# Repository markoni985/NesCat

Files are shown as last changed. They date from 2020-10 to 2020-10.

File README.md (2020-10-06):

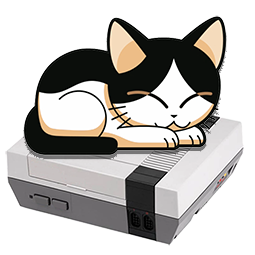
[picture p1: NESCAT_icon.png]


# NesCat 0.5

NESCAT by Nathalis
prototype version: 0.5 (c)2020
Enhanced version Nintendo Emulator for ESP32

Requirements: ESP32 WEMOS D1 MINI, ST7789 LCD, MICROSD CARD slot,
PCM5102 I2S AUDIO MODULE, OTHER PARTS...

### FEATURES:

- MicroSD card support
- 240*240 1.3" LCD ST7789 display                  
- Composite TV OUT Video PAL
- I2S AUDIO support PCM5102 module
- PS2 (USB) KEYBOARD support (wireless not work)
- huge NES ROMs up to 512kB (read from FLASH)
- PS4 DualShock BlueTooth Gamepad (experimental)

Only for personal & educational use! 

### DIAGRAM (NEW)
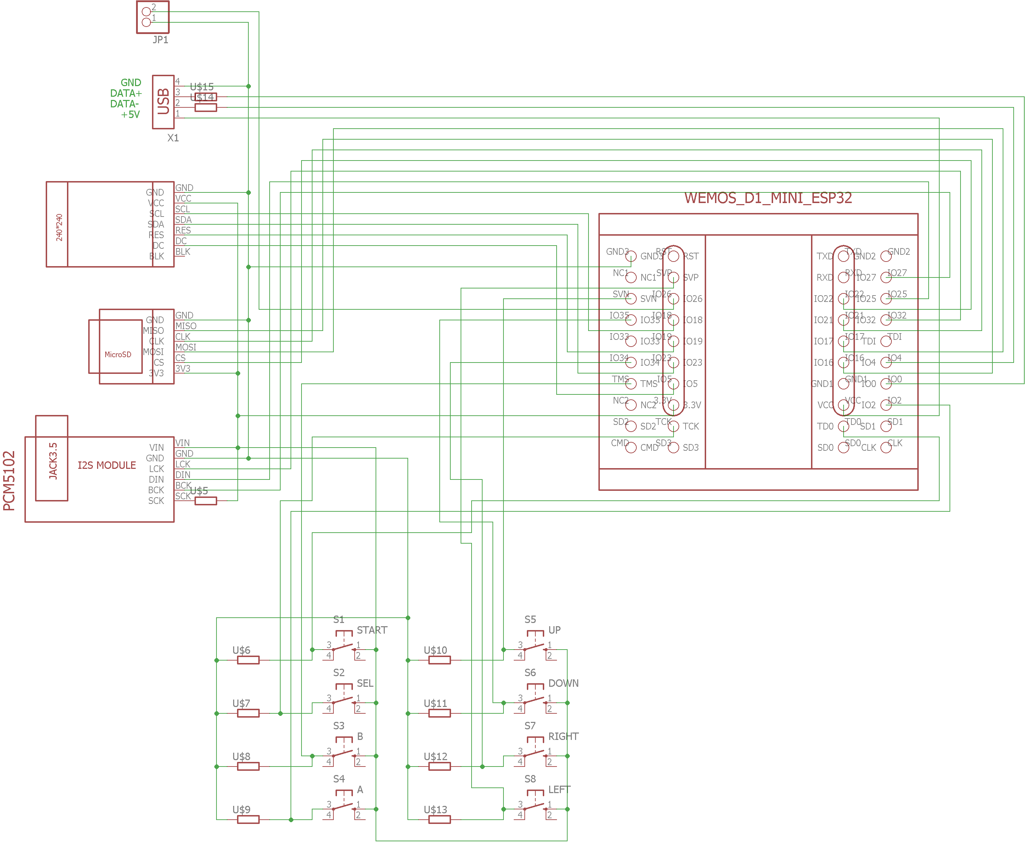
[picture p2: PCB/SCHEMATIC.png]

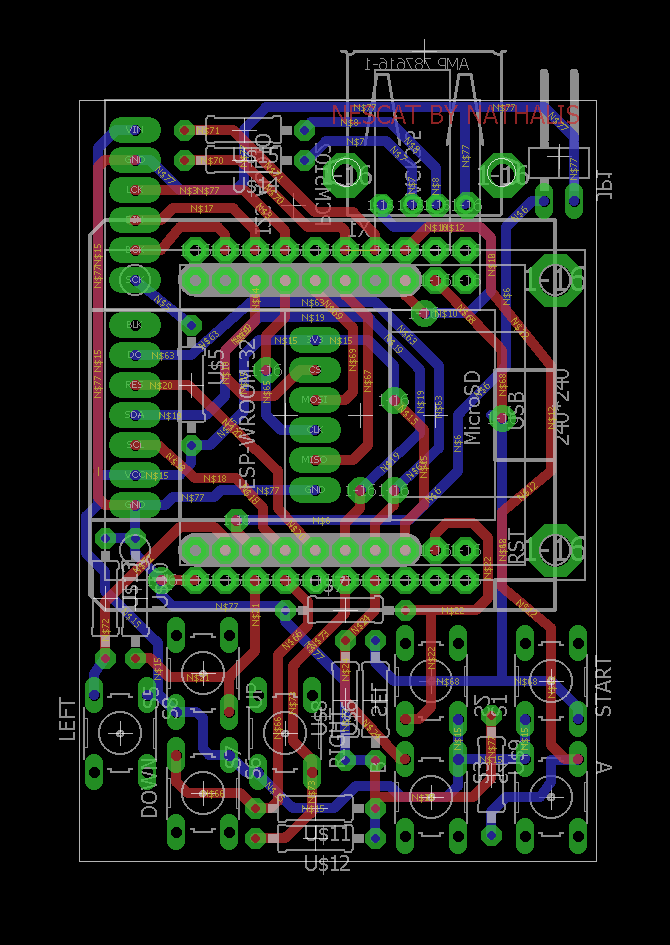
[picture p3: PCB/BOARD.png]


### IMAGES:

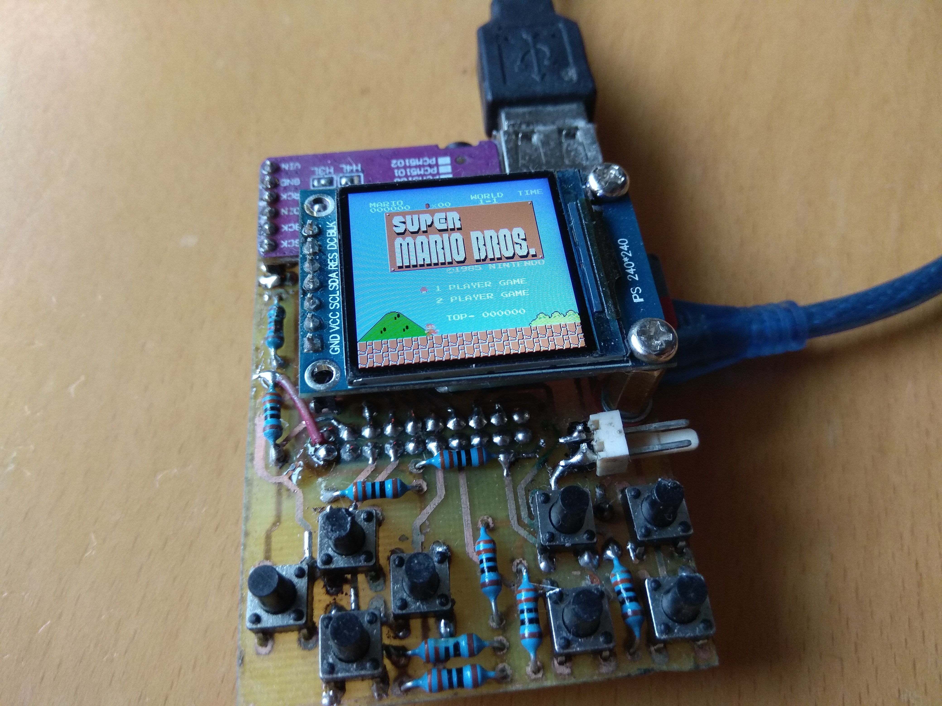
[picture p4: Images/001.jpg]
Image description

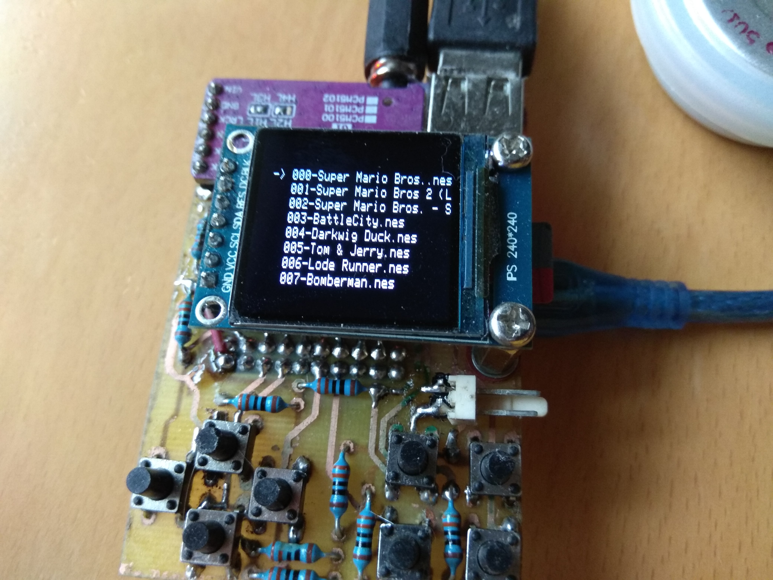
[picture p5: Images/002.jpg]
Image description

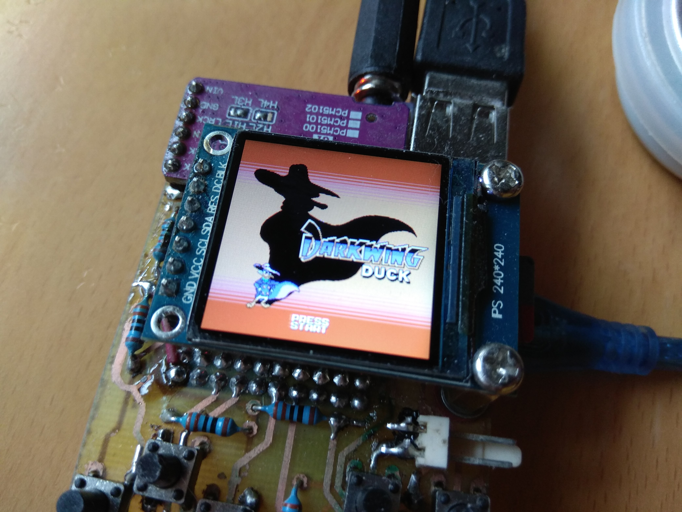
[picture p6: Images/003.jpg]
Image description

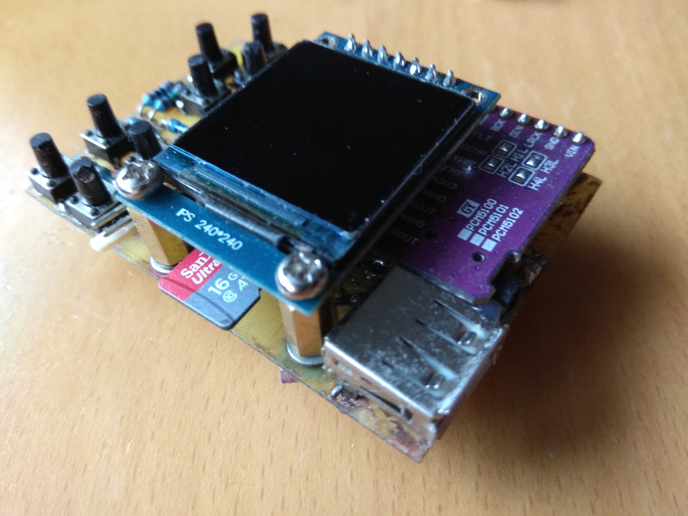
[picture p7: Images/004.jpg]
Image description

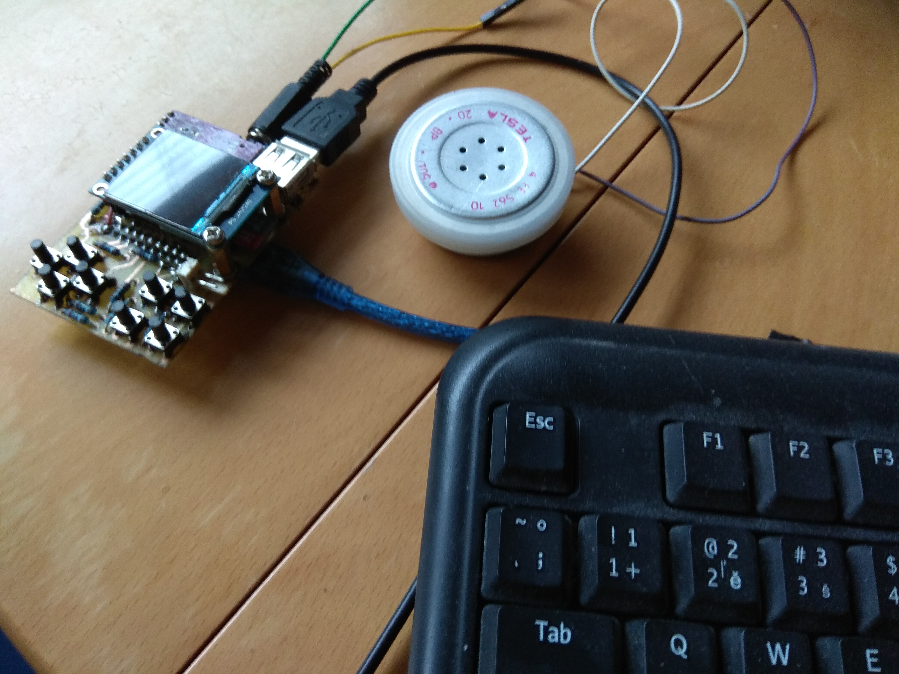
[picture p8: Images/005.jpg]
Image description

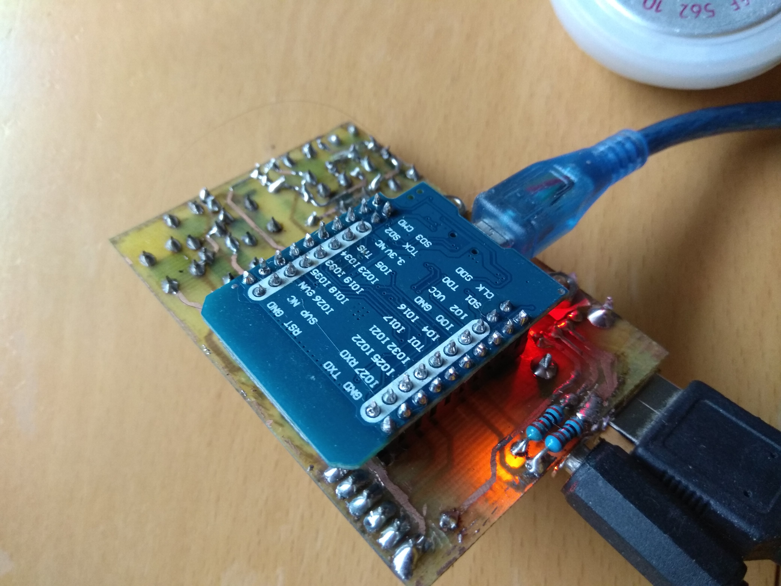
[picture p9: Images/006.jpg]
Image description

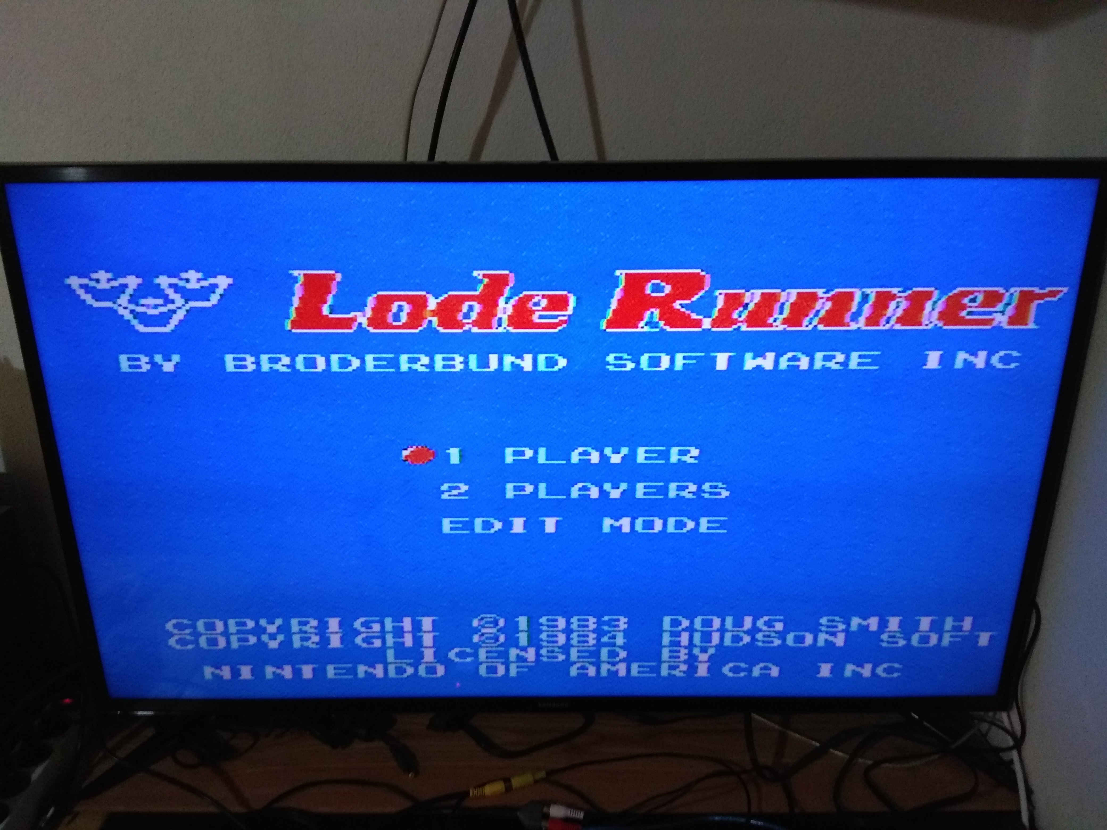
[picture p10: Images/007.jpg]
Image description

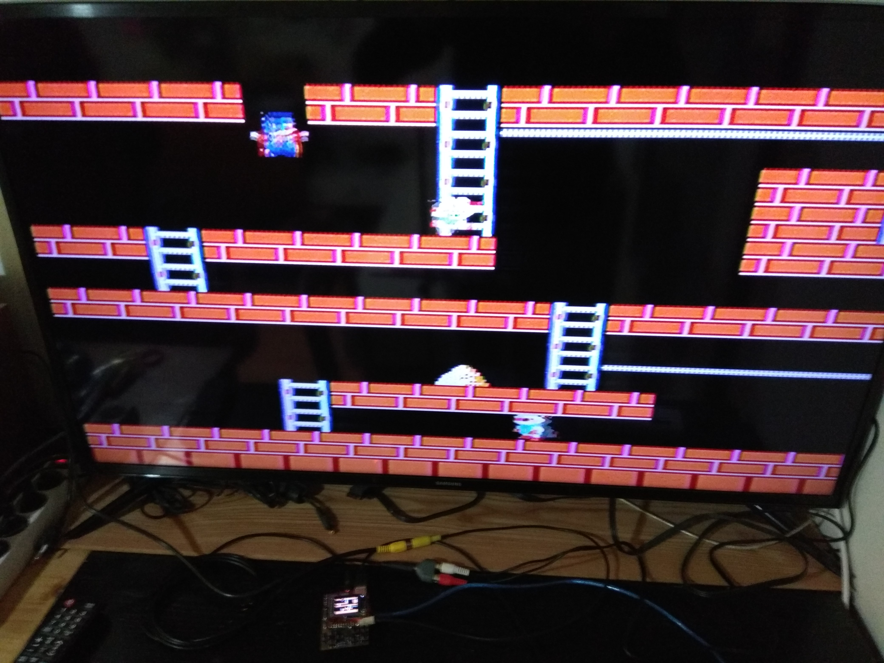
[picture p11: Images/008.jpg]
Image description

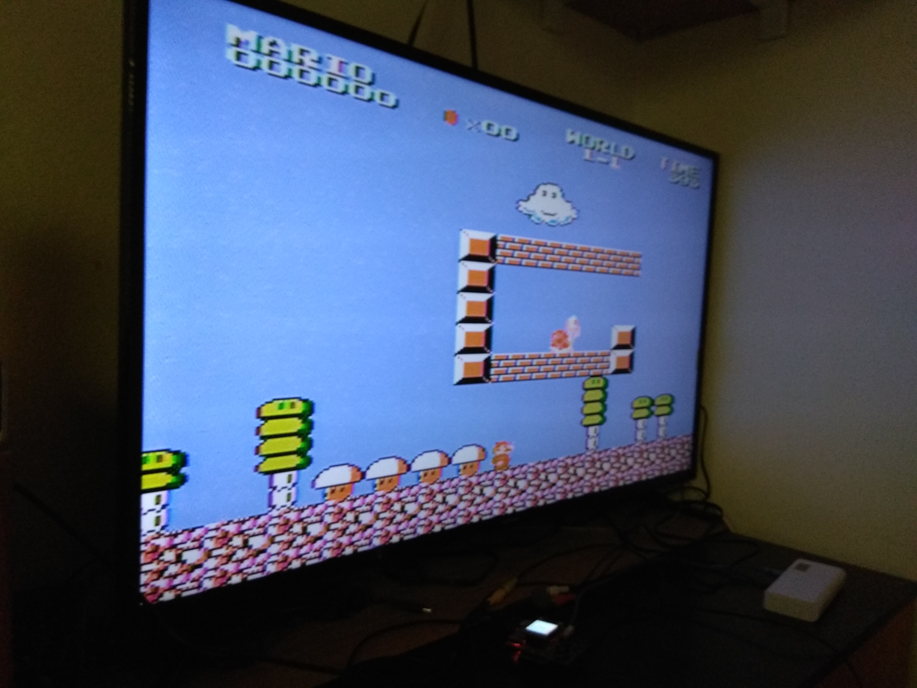
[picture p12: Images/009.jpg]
Image description

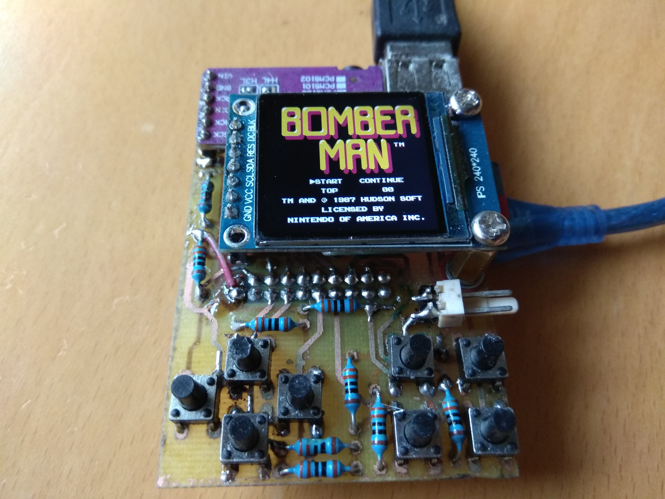
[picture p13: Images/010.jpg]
Image description

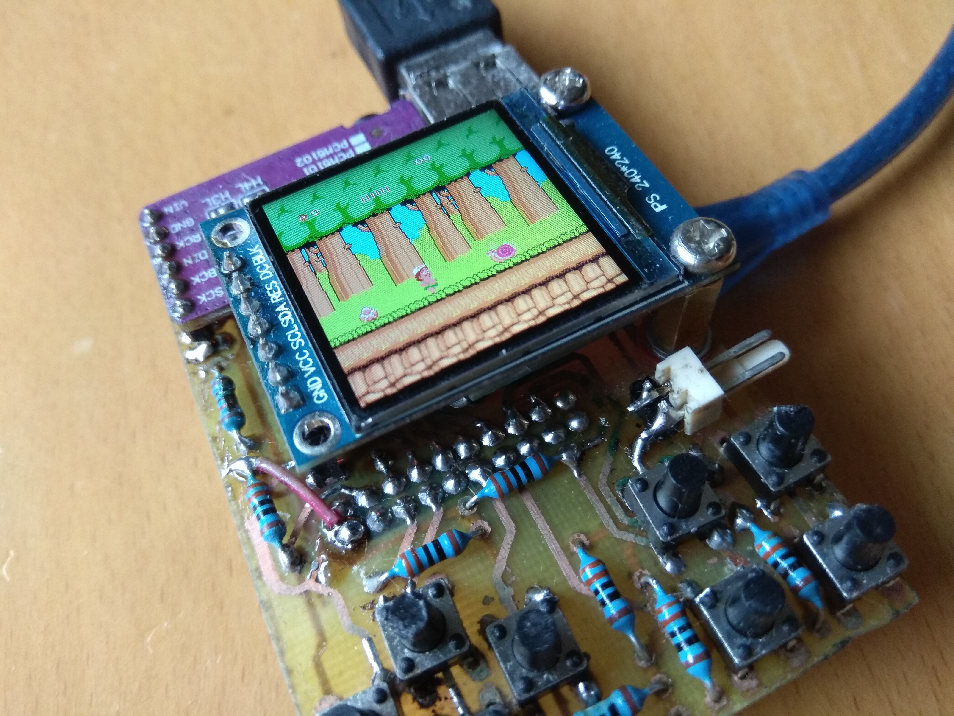
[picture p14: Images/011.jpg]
Image description

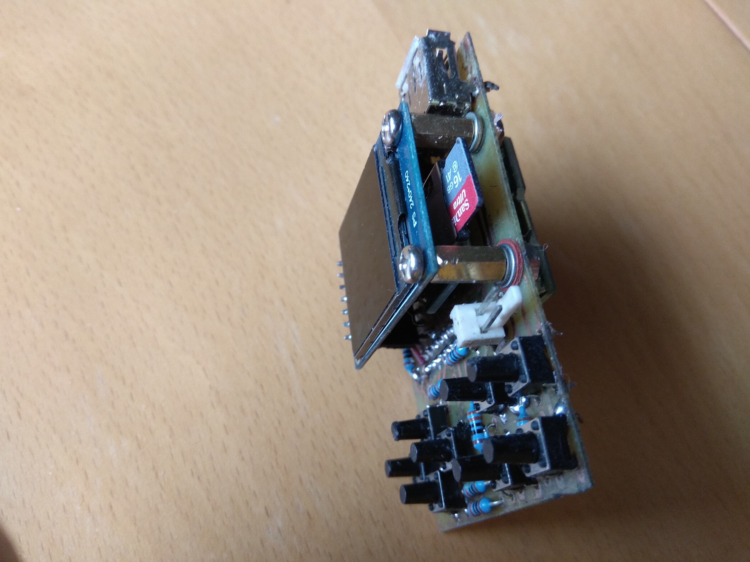
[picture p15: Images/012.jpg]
Image description


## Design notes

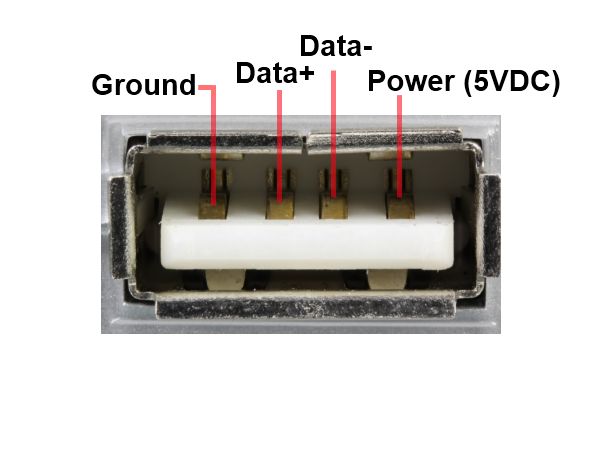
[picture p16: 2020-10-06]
Resources/usb2-Apinout-600.jpg

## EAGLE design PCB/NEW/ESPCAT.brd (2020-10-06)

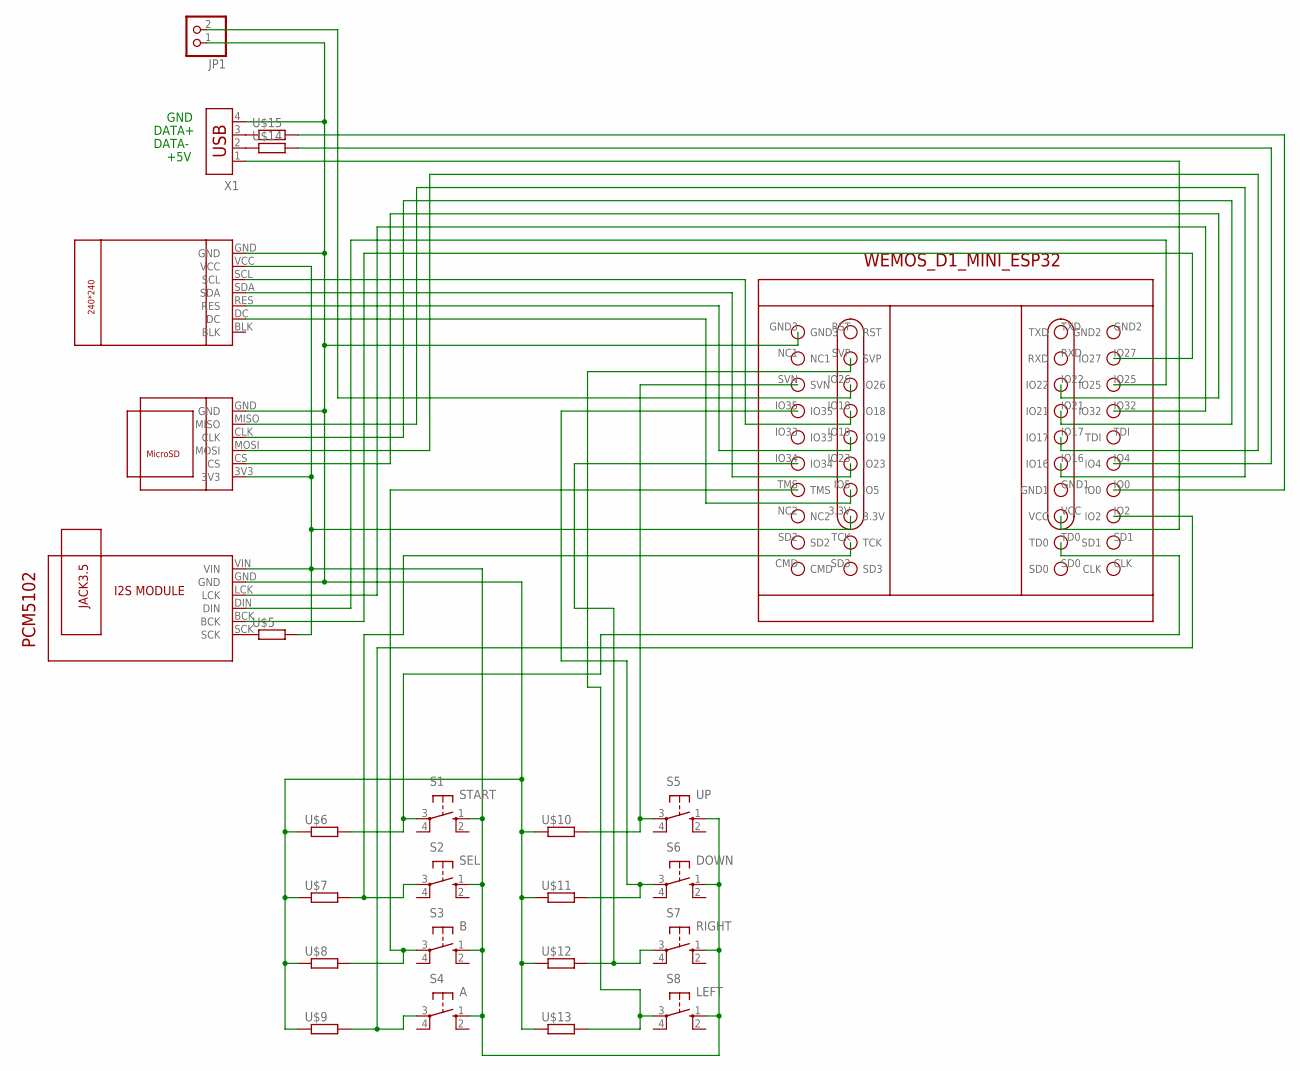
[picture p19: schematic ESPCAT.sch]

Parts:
JP1: PINHD-1X2/90; 1X02/90
S1: START; B3F-10XX
S2: SEL; B3F-10XX
S3: B; B3F-10XX
S4: A; B3F-10XX
S5: UP; B3F-10XX
S6: DOWN; B3F-10XX
S7: RIGHT; B3F-10XX
S8: LEFT; B3F-10XX
U$1: WEMOS_D1_MINI_ESP32
U$2: ST7789-1.3INCH
U$3: MICROSD-CARD-MODULE
U$4: I2S-MODULE-PCM5102A-LITE
U$5, U$6, U$7, U$8, U$9, U$10, U$11, U$12, U$13, U$14, U$15: R-RESISTORR-0207/10H; R-0207/10H
X1: USB-787616; USB

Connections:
unnamed: U$1.IO32, U$4.LCK
unnamed: U$4.SCK, U$5.1
unnamed: JP1.2, U$1.IO26
unnamed: U$14.1, X1.2
unnamed: U$15.1, X1.3
unnamed: U$1.VCC, X1.1
unnamed: S4.3, U$1.IO2, U$9.2
unnamed: U$1.IO27, U$4.BCK
unnamed: S1.1 (S), S2.1 (S), S3.1 (S), S4.1 (S), S5.1 (S), S6.1 (S), S7.1 (S), S8.1 (S), U$1.3.3V, U$2.VCC, U$3.3V3, U$4.VIN, U$5.2
unnamed: U$1.IO25, U$4.DIN
unnamed: U$1.IO18, U$2.SCL
unnamed: U$1.IO23, U$2.SDA
unnamed: U$1.IO19, U$2.RES
unnamed: S5.3, U$1.SVN, U$10.2
unnamed: S2.3, U$1.TCK, U$7.2
unnamed: S3.3, U$1.TMS, U$8.2
unnamed: U$1.IO5, U$2.DC
unnamed: U$1.IO22, U$3.CS
unnamed: U$1.IO21, U$3.CLK
unnamed: S6.3, U$1.IO35, U$11.2
unnamed: U$1.IO16, U$3.MISO
unnamed: S1.3, U$1.TD0, U$6.2
unnamed: U$1.IO17, U$3.MOSI
unnamed: U$1.IO4, U$14.2
unnamed: U$1.IO0, U$15.2
unnamed: S8.3, U$1.SVP, U$13.2
unnamed: S7.3, U$1.IO34, U$12.2
unnamed: JP1.1, U$1.GND3, U$2.GND, U$3.GND, U$4.GND, U$6.1, U$7.1, U$8.1, U$9.1, U$10.1, U$11.1, U$12.1, U$13.1, X1.4

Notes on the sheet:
+5V
DATA-
DATA+
GND

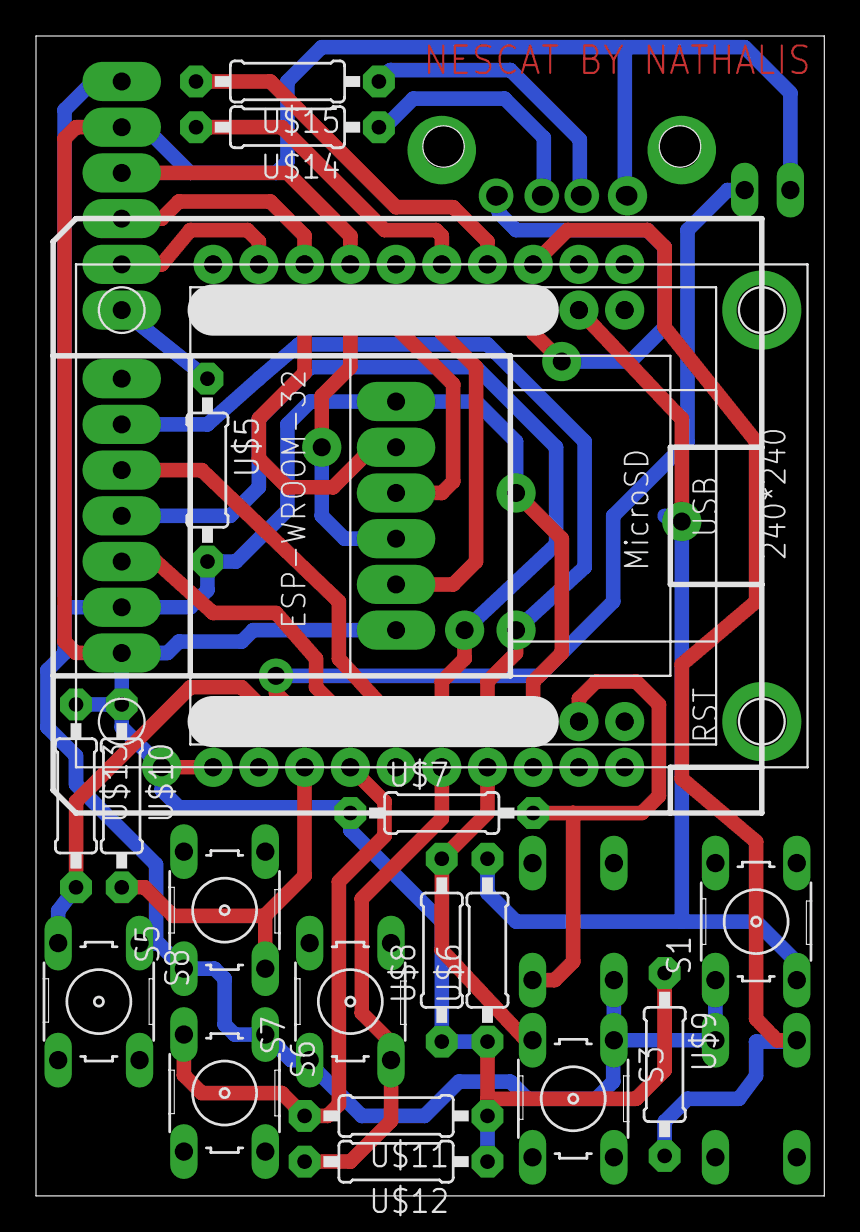
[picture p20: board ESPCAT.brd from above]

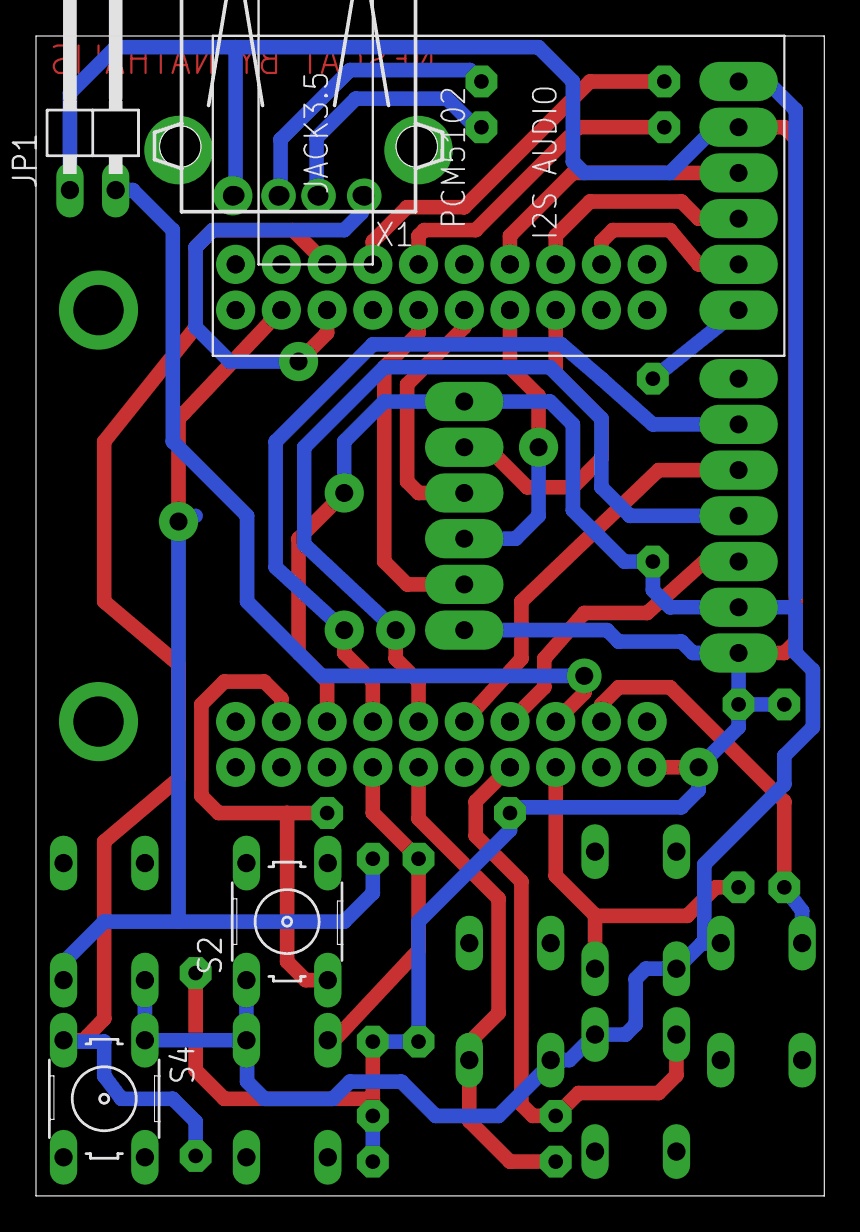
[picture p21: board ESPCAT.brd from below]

Board: 2 copper layers, 43.8 x 64.4 mm, 25 parts (5 on the bottom side), 28 nets.

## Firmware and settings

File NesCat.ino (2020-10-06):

//MEOW?                                                           
//                                                ▄▄         
//                        ▓▀██▄                ▄▓█▀▓▓       
//                       ▐▌░ ▀███▄          ▄███▀  ░▓▒      
//                       ▓▌ ░░░▒██████████████▓░▒░░░▓▌      
//             ▄▄▄██████▄▓▌ ░▒▒▒▒▀██████████████▄░░░▓▌      
//          ▄█████████████▌░▒▒▒▒▒▄████████████████▒▐▌       
//        ▄████████████████▌▄▄▄█████████▒░█████████▓▒       
//       ▐████████████████████████████▓    ▀████████░       
//      ▐███████▀▒▒▄▒    ▓██████████▓       ▀▓██████▒       
//      ▐▌    ▒▒     ░▓▒ ▓███████▀▀▀▓▓▄    ▄▓▓▀▀███▌        
//     ▐▓▌             ░▒▒▓▓▒░        ▀▀  ▀▀     ▐▓▌        
//    ▐██▌              ▒▒▒▓▓▓▒         ▒▒     ▄▓█▓▒         
//   ▐████▒            ▒▓▒ ░▓▓▓▓▒▒▒▒▒▒▒▓▓▓▄▓▓▓▓███▀░░░░░░   
//   ▐██████▓▄▄▄▄▄▄▄▄▄▄▓▓▄▄░            ░▓▒ ▒░░▓▓░░░░░      
//   ░▓█████████████████████▓▒▄▄▄▄▄▄▄▄▓▓▓▓▓▓▓▓▓█▓░░░        
//▒▒▒░▒▒▓██████████████████▀▀▀▀▀▀▀▀▀▀▀▀▀▀▒▒▒    ░░     ▒▒   
//▒▒▒▒▒▒▒▒▒▒▒▒▒░░░░░░░░░░░░░░░░░▄▄▒▒▒▒▒▒▒▒░ ░░░░     ▒▓▒    
//▒▒▒▒▒▒▒▒▒▒▒▒▒▒▒▒▒▒▒▒▒▒░░░░░░▄▓██████▓▒    ░      ░▓▓▀     
//▓▓▓▓▓▓▒▒▒▒▒▒▒▒▒▒▒▒▒▒▒▒▒▒▒▒▒▓███████▀    ░      ▄▓▓▓       
// ▓▓▓▓▓▓▓▓▓▓▓▓▓▓▄▒▒▒▒▒▒▒▒▒▒░▓██████▌▒▒▒▒░     ▒▓▒▒         
//  ▓▓▓▓▓▓▓█▓▓▓▓▓▓▓▓▓▓▓▓▓▓▒▒▒▓██████▌▒▒▒▒▒   ▒▓▒▒           
//     ▀▀▀▀▓▓▓▓▓▓▓▓▓▓▓▓▓▓▓▓▓▓▓██████▌▒▒▒▒▒░ ▓▒▒░            
//             ▀▀▀▀▓▓▓▓▓▓▓▓▓▓▓███████▓▓▓▓▓▓▒▒               
//                      ▀▀▀▓▓▓███████▓▓▓▓▓▒                 
//                               ▀▀▀▀▓▓▓▓▒                                                                              
//********************************************************************************
//*                                                                              *
//*   NESCAT by Nathalis                                                         *
//*   prototype version: 0.5 (c)2020                                             *
//*   Enhanced version Nintendo Emulator for ESP32                               *
//*                                                                              *
//*   Requirements: ESP32 WEMOS D1 MINI, SD7789 LCD, MICROSD CARD slot,          *
//*   PCM5102 I2S AUDIO MODULE, OTHER PARTS...                                   *
//*                                                                              *
//*   Only for personal & educational use!                                       *
//*   (GPL-3.0 License)                                                          *
//*                                                                              *
//********************************************************************************
//*                                                                              *
//*   features:                                                                  *
//*   - MicroSD card support                                                     *
//*   - 240*240 1.3" LCD SD7789 display                                          *
//*   - Composite TV OUT Video PAL                                               *
//*   - I2S AUDIO support PCM5102 module                                         *
//*   - PS2 (USB) KEYBOARD support (wireless not work)                           *
//*   - huge NES ROMs up to 512kB (read from FLASH)                              *
//*   - PS4 DualShock BlueTooth Gamepad (experimental)                           *
//*                                                                              *
//*   to do:                                                                     *
//*   - ESP32-WROVER PSRAM module support                                        *
//*   - battery install                                                          *
//*   - ESP32 MP3-Player support                                                 *
//*                                                                              *
//*                                                                              *
//********************************************************************************

#define NES_FOLDER ("/NES/")

#define BLUETOOTH_ENABLED
#define KEYBOARD_ENABLED
#define LCD_ENABLED true
#define SOUND_ENABLED true
#define COMPOSITE_VIDEO_ENABLED

#define DEBUG true //Serial debugging enable.
#define DEBUGEXTRA false //Extra Serial debugging enable.

//================================================================================

#define PIN_UP     39  //SVN
#define PIN_DOWN   35  //IO35
#define PIN_LEFT   36  //SVP
#define PIN_RIGHT  34  //IO34
#define PIN_A      2   //IO2
#define PIN_B      14  //TMS
#define PIN_START  15  //TDO
#define PIN_SELECT 13  //TCK

///!!! do not forget 1KOHM resistors

#define KEYBOARD_DATA 4  /// ---[ 1K ]--- // -D
#define KEYBOARD_CLK 0  /// ---[ 1K ]--- // +D

//COMPOSITE_VIDEO: - //DAC_GPIO25_CHANNEL or DAC_GPIO26_CHANNEL
#define VIDEO_OUT (DAC_GPIO26_CHANNEL)

//AUDIO_i2S:
#define I2S_BCK_IO (GPIO_NUM_27) //BCK
#define I2S_WS_IO  (GPIO_NUM_32) //LCK
#define I2S_DO_IO  (GPIO_NUM_25) //DIN
#define I2S_DI_IO  (-1)

//LCD_ST7789:
#define TFT_CS   -1  // define chip select pin
#define TFT_DC    5  // define data/command pin
#define TFT_RST  19
#define TFT_MOSI 23  // Data out (SDA) //better not change
#define TFT_SCLK 18  // Clock out (SCL) //better not change

//micro_SD_Card:
#define SOFTSD_MOSI_PIN (GPIO_NUM_17)
#define SOFTSD_MISO_PIN (GPIO_NUM_16)
#define SOFTSD_SCK_PIN (GPIO_NUM_21)
#define SD_CS_PIN GPIO_NUM_22

//================================================================================

//********************************************************************************
//MAIN LIBRARIES:

#include <esp_task_wdt.h>

#include "esp_types.h"
#include "esp_heap_caps.h"
#include "esp_attr.h"
#include "esp_intr_alloc.h"
#include "esp_err.h"
#include "soc/gpio_reg.h"
#include "soc/rtc.h"
#include "soc/soc.h"
#include "soc/i2s_struct.h"
#include "soc/i2s_reg.h"
#include "soc/ledc_struct.h"
#include "soc/rtc_io_reg.h"
#include "soc/io_mux_reg.h"
#include "rom/gpio.h"
#include "rom/lldesc.h"
#include "driver/periph_ctrl.h"
#include "driver/dac.h"
#include "driver/gpio.h"
//********************************************************************************

//--------------------------------------------------------------------------------
//SPI FLASH MEMORY ACCESS:
#include "esp_spi_flash.h"

#define SPI_FLASH_ADDRESS 0x00300000 //0x00300000 working (empty flash area)
#define SPI_FLASH_SECTOR_SIZE 0x1000 //4kB = better not change

uint32_t FILE_ROM_SIZE = 0;
uint32_t FLASH_ROM_SIZE = 0;

//constant data pointer for direct access
const void *ROM;

spi_flash_mmap_handle_t handle1;

uint8_t flashdata[4096] = {0}; //4kB buffer

//--------------------------------------------------------------------------------
//DRAM MEMORY ACCESS:
//--------------------------------------------------------------------------------

char* ROMFILENAME; //NES load File name
unsigned char *rom = 0; //Actual ROM pointer

//********************************************************************************
//Allocated MEMORY variables:

uint8_t* SCREENMEMORY[256];  //256*256 bytes
uint16_t SCREENBUFFER[256];  //512 bytes

//********************************************************************************
//********************************************************************************
//PALETTES:

const uint32_t nes_32bit[64] = { //4colors Green-Yellow-Red-Blue
  0x2D253469, 0x000000D9, 0x000000A1, 0x0F111CA1, 0x001F3F70, 0x0024491C, 0x06264900, 0x061F3B00,
  0x12162300, 0x2D0B0000, 0x27090000, 0x21080000, 0x1806004D, 0x14141414, 0x14141414, 0x14141414,
  0x453950A1, 0x2D0B00D9, 0x210800D9, 0x181C2DD9, 0x002F5EAF, 0x0031624D, 0x153B6C00, 0x2139620E,
  0x2D304900, 0x45110000, 0x3F0F0000, 0x3F0F0038, 0x330C0077, 0x14141414, 0x14141414, 0x14141414,
  0x5D4D6CD9, 0x451D18D9, 0x33232DD9, 0x2D2C42D9, 0x2D416CD9, 0x213E6C85, 0x2D416C4D, 0x3C456C38,
  0x45476C00, 0x5D3F5015, 0x51272646, 0x5D2A2685, 0x571500BD, 0x2D253469, 0x14141414, 0x14141414,
  0x5D4D6CD9, 0x543846D9, 0x453950D9, 0x45405ED9, 0x45476CD9, 0x3C456CA8, 0x4E48699A, 0x544B6C93,
  0x514A6C69, 0x5D465E69, 0x5D3F50A1, 0x5D3F50BD, 0x5D1700D9, 0x514A6CD9, 0x14141414, 0x14141414,
};

const uint16_t nes_16bit[64] = {
  0x7BEF, 0x001F, 0x0017, 0x4157, 0x9010, 0xA804, 0xA880, 0x88A0,
  0x5180, 0x03C0, 0x0340, 0x02C0, 0x020B, 0x0000, 0x0000, 0x0000,
  0xBDF7, 0x03DF, 0x02DF, 0x6A3F, 0xD819, 0xE00B, 0xF9C0, 0xE2E2,
  0xABE0, 0x05C0, 0x0540, 0x0548, 0x0451, 0x0000, 0x0000, 0x0000,
  0xFFDF, 0x3DFF, 0x6C5F, 0x9BDF, 0xFBDF, 0xFAD3, 0xFBCB, 0xFD08,
  0xFDC0, 0xBFC3, 0x5ECA, 0x5FD3, 0x075B, 0x7BCF, 0x0000, 0x0000,
  0xFFFF, 0xA73F, 0xBDDF, 0xDDDF, 0xFDDF, 0xFD38, 0xF696, 0xFF15,
  0xFECF, 0xDFCF, 0xBFD7, 0xBFDB, 0x07FF, 0xFEDF, 0x0000, 0x0000,
};
//********************************************************************************

//********************************************************************************

#ifdef BLUETOOTH_ENABLED
//Bluetooth_PS4_DualShock_support_for_ESP32:
#include "src/hid_server/hid_server.h"
#endif

//COMPOSITE_VIDEO_OUT
#ifdef COMPOSITE_VIDEO_ENABLED
#include "src/compositevideo/video.h"
#endif

//********************************************************************************

//********************************************************************************
//LIBRARIES:

//LCD_ST7789:
#include <Adafruit_GFX.h>    // Core graphics library
#include <Adafruit_ST7789.h> // Hardware-specific library for ST7789
#include <SPI.h>

//micro_SD_Card:
#include <SdFat.h>
///#define ENABLE_SOFTWARE_SPI_CLASS 1  // Must be set in SdFat/SdFatConfig.h !!!

//AUDIO_i2S:
#ifdef SOUND_ENABLED
#include "driver/i2s.h"
#endif
//********************************************************************************
//CONFIGS:
//--------------------------------------------------------------------------------

//LCD_ST7789
#define ST7789_DRIVER     // Configure all registers
#define TFT_WIDTH  240
#define TFT_HEIGHT 240
#define LOAD_GLCD   // Font 1. Original Adafruit 8 pixel font needs ~1820 bytes in FLASH
#define LOAD_FONT2  // Font 2. Small 16 pixel high font, needs ~3534 bytes in FLASH, 96 characters
#define LOAD_FONT4  // Font 4. Medium 26 pixel high font, needs ~5848 bytes in FLASH, 96 characters
Adafruit_ST7789 tft = Adafruit_ST7789(TFT_CS, TFT_DC, TFT_RST);

//micro_SD_Card
const uint8_t SOFT_MOSI_PIN = SOFTSD_MOSI_PIN;
const uint8_t SOFT_MISO_PIN = SOFTSD_MISO_PIN;
const uint8_t SOFT_SCK_PIN = SOFTSD_SCK_PIN;
SdFatSoftSpi<SOFT_MISO_PIN, SOFT_MOSI_PIN, SOFT_SCK_PIN> SD;
File fp;
SdFile dirFile; //for root directory file listing
SdFile file;
//********************************************************************************
//********************************************************************************
//********************************************************************************

//--------------------------------------------------------------------------------
///TYPEDEFS:

// Define this if running on little-endian (x86) systems
#define  HOST_LITTLE_ENDIAN //!!! important for Arduino
#define  ZERO_LENGTH 0

// quell stupid compiler warnings
#define  UNUSED(x)   ((x) = (x))

// 16Bit Color set
#define BLACK           0x0000
#define RED             0xF800
#define GREEN           0x07E0
#define BLUE            0x102E
#define CYAN            0x07FF
#define MAGENTA         0xF81F
#define YELLOW          0xFFE0
#define WHITE           0xFFFF
//--------------------------------------------------------------------------------
//================================================================================
//AUDIO_SETUP
#define DEFAULT_SAMPLERATE 24000
#define DEFAULT_FRAGSIZE 60 //max.256, default 240

//VIDEO_SETUP
// Visible (NTSC) screen height
#ifndef NES_VISIBLE_HEIGHT
#define  NES_VISIBLE_HEIGHT   240
#endif // !NES_VISIBLE_HEIGHT 
#define  NES_SCREEN_WIDTH     256
#define  NES_SCREEN_HEIGHT    240

#define PAL

// NTSC = 60Hz, PAL = 50Hz
#ifdef PAL
#define  NES_REFRESH_RATE     50
#else
#define  NES_REFRESH_RATE     60
#endif

#define  MAX_MEM_HANDLERS     32

#define DEFAULT_WIDTH NES_SCREEN_WIDTH
#define DEFAULT_HEIGHT NES_VISIBLE_HEIGHT

#define  NES_CLOCK_DIVIDER    12  //default: 12
//#define  NES_MASTER_CLOCK     21477272.727272727272
#define  NES_MASTER_CLOCK     (236250000 / 11)
#define  NES_SCANLINE_CYCLES  (1364.0 / NES_CLOCK_DIVIDER)
#define  NES_FIQ_PERIOD       (NES_MASTER_CLOCK / NES_CLOCK_DIVIDER / 60)

#define  NES_RAMSIZE          0x800

#define  NES6502_NUMBANKS  16
#define  NES6502_BANKSHIFT 12
#define  NES6502_BANKSIZE  (0x10000 / NES6502_NUMBANKS)
#define  NES6502_BANKMASK  (NES6502_BANKSIZE - 1)


//********************************************************************************
//********************************************************************************
uint8_t NES_POWER = 1;
//********************************************************************************
QueueHandle_t vidQueue;
//********************************************************************************

//********************************************************************************
uint8_t JOY_UP = 0;
uint8_t JOY_DOWN = 0;
uint8_t JOY_LEFT = 0;
uint8_t JOY_RIGHT = 0;
uint8_t JOY_CROSS = 0;
uint8_t JOY_SQUARE = 0;
uint8_t JOY_CIRCLE = 0;
uint8_t JOY_TRIANGLE = 0;
uint8_t JOY_SHARE = 0; //(START)
uint8_t JOY_OPTIONS = 0; //(SELECT)
//********************************************************************************

//********************************************************************************
uint8_t scancode = 0;
boolean keyup = false;
byte keymap[256];

IRAM_ATTR void USB_KEYBOARD() {
#ifdef KEYBOARD_ENABLED
  if (keymap[0x75] == 0) {
    JOY_UP = 1;
  }
  else JOY_UP = 0;
  if (keymap[0x72] == 0) {
    JOY_DOWN = 1;
  }
  else JOY_DOWN = 0;
  if (keymap[0x6B] == 0) {
    JOY_LEFT = 1;
  }
  else JOY_LEFT = 0;
  if (keymap[0x74] == 0) {
    JOY_RIGHT = 1;
  }
  else JOY_RIGHT = 0;

  if (keymap[0x11] == 0 || keymap[0x1A] == 0) JOY_CROSS = 1; //ALT or X
  else JOY_CROSS = 0;
  if (keymap[0x14] == 0 || keymap[0x22] == 0) JOY_SQUARE = 1; //CTRL or Z
  else JOY_SQUARE = 0;
  if (keymap[0x5A] == 0) JOY_SHARE = 1;
  else JOY_SHARE = 0;
  if (keymap[0x66] == 0) JOY_OPTIONS = 1;
  else JOY_OPTIONS = 0;

  if (keymap[0x76] == 0) {
    JOY_SHARE = 1;
    JOY_OPTIONS = 1;
  } else if (JOY_SHARE == 1 && JOY_OPTIONS == 1 ) {
    JOY_SHARE = 0;
    JOY_OPTIONS = 0;
  }

  if (DEBUGEXTRA) {
    if (JOY_UP) Serial.print("UP.");
    if (JOY_DOWN) Serial.print("DOWN.");
    if (JOY_LEFT) Serial.print("LEFT.");
    if (JOY_RIGHT) Serial.print("RIGHT.");
    if (JOY_SHARE) Serial.print("START.");
    if (JOY_OPTIONS) Serial.print("SELECT.");
    if (JOY_CROSS) Serial.print("A.");
    if (JOY_SQUARE) Serial.print("B.");
    Serial.println();
  }
#endif
}
//********************************************************************************

void IRAM_ATTR kb_interruptHandler(void) {
#ifdef KEYBOARD_ENABLED
  static uint8_t bitcount = 0;
  uint8_t val;

  int clock = digitalRead(KEYBOARD_CLK);
  if (clock == 0) {
    return;
  }

  val = digitalRead(KEYBOARD_DATA);
  if (DEBUGEXTRA) Serial.print(".");
  if (DEBUGEXTRA) Serial.print(val);

  bitcount++;

  if (bitcount > 1 && bitcount < 10) { //8bits
    scancode |= ((val & 1) << (bitcount - 2));
  }

  if (bitcount > 10) {
    if (keyup == true) {
      keymap[scancode] = 1;

      if (DEBUGEXTRA) {
        Serial.print(" {");
        Serial.print(scancode, HEX);
        Serial.print("} ");
      }
      keyup = false;
    } else {
      keymap[scancode] = 0;
    }

    if (scancode  == 0xF0  ) {
      keyup = true;
    } else {
      keyup = false;
    }

    if (DEBUGEXTRA) {
      Serial.print("[");
      Serial.print(scancode, HEX);
      Serial.println("]");
    }

    USB_KEYBOARD();

    bitcount = 0;
    scancode = 0;
  }
#endif
}

void kb_begin() {
#ifdef KEYBOARD_ENABLED
  pinMode(KEYBOARD_DATA, INPUT_PULLUP);
  pinMode(KEYBOARD_CLK, INPUT_PULLUP);
  digitalWrite(KEYBOARD_DATA, true);
  digitalWrite(KEYBOARD_CLK, true);
  attachInterrupt(digitalPinToInterrupt(KEYBOARD_CLK), kb_interruptHandler, RISING);
  memset(keymap, 1, sizeof(keymap));
#endif
}
//********************************************************************************

//********************************************************************************
uint8_t buf[64] = {0}; //JoyRead buffer...
int num_get = 0;
IRAM_ATTR static void PS4_JOY() {
#ifdef BLUETOOTH_ENABLED

  // update the bluetooth edr/hid stack
  ///hid_update();

  //read data from JoyStick
  num_get = hid_get(buf, sizeof(buf) - 1); // called from emulation loop
//********************************************************************************

  if ((num_get != -1) && buf[0] == 161) { // If connected then read JoyStick

    uint8_t JOYBUTTON = buf[6];
    uint8_t JOYBUTTON2 = buf[7];
    ///Serial.println(JOYBUTTON);

    if ( JOYBUTTON % 8 == 0) {
      JOY_UP = 1;
    }
    else if ( JOYBUTTON % 8 == 1) {
      JOY_UP = 1;
      JOY_RIGHT = 1;
      JOY_DOWN = 0;
      JOY_LEFT = 0;
    }
    else if ( JOYBUTTON % 8 == 2) {
      JOY_RIGHT = 1;
      JOY_DOWN = 0;
      JOY_LEFT = 0;
      JOY_UP = 0;
    }
    else if ( JOYBUTTON % 8 == 3) {
      JOY_RIGHT = 1;
      JOY_DOWN = 1;
      JOY_LEFT = 0;
      JOY_UP = 0;
    }
    else if ( JOYBUTTON % 8 == 4) {
      JOY_DOWN = 1;
      JOY_LEFT = 0;
      JOY_RIGHT = 0;
      JOY_UP = 0;
    }
    else if ( JOYBUTTON % 8 == 5) {
      JOY_DOWN = 1;
      JOY_LEFT = 1;
      JOY_RIGHT = 0;
      JOY_UP = 0;
    }
    else if ( JOYBUTTON % 8 == 6) {
      JOY_LEFT = 1;
      JOY_UP = 0;
      JOY_DOWN = 0;
      JOY_RIGHT = 0;
    }
    else if ( JOYBUTTON % 8 == 7) {
      JOY_LEFT = 1;
      JOY_UP = 1;
      JOY_DOWN = 0;
      JOY_RIGHT = 0;
    }
    if (((JOYBUTTON >> 3) & 1) != 0) {
      JOY_UP = 0;
      JOY_DOWN = 0;
      JOY_LEFT = 0;
      JOY_RIGHT = 0;
    }

    if ( JOYBUTTON > 8 && ((JOYBUTTON >> 4) & 1) != 0) {
      JOY_SQUARE = 1;
    }
    else if (((JOYBUTTON >> 4) & 1) == 0) {
      JOY_SQUARE = 0;
    }
    if ( JOYBUTTON > 8 && ((JOYBUTTON >> 4) & 2) != 0) {
      JOY_CROSS = 1;
    }
    else if (((JOYBUTTON >> 4) & 2) == 0) {
      JOY_CROSS = 0;
    }
    if ( JOYBUTTON > 8 && ((JOYBUTTON >> 4) & 4) != 0) {
      JOY_CIRCLE = 1;
    }
    else if (((JOYBUTTON >> 4) & 4) == 0) {
      JOY_CIRCLE = 0;
    }
    if ( JOYBUTTON > 8 && ((JOYBUTTON >> 4) & 8) != 0) {
      JOY_TRIANGLE = 1;
    }
    else if (((JOYBUTTON >> 8) & 1) == 0) {
      JOY_TRIANGLE = 0;
    }

    if (JOYBUTTON2 == 0) {
      JOY_SHARE = 0;
      JOY_OPTIONS = 0;
    }
    if ( JOYBUTTON2 > 8 && ((JOYBUTTON2 >> 4) & 1) != 0) {
      JOY_SHARE = 1;
    }
    if ( JOYBUTTON2 > 8 && ((JOYBUTTON2 >> 4) & 2) != 0) {
      JOY_OPTIONS = 1;
    }
  }
  if (DEBUGEXTRA) {
    if (JOY_UP) Serial.print("UP.");
    if (JOY_DOWN) Serial.print("DOWN.");
    if (JOY_LEFT) Serial.print("LEFT.");
    if (JOY_RIGHT) Serial.print("RIGHT.");
    if (JOY_SHARE) Serial.print("START.");
    if (JOY_OPTIONS) Serial.print("SELECT.");
    if (JOY_CROSS) Serial.print("A.");
    if (JOY_SQUARE) Serial.print("B.");
    Serial.println();
  }

#endif
}
//********************************************************************************
/* read counters */
int pad0_readcount, pad1_readcount, ppad_readcount, ark_readcount;

void input_strobe(void) {
  pad0_readcount = 0;
  pad1_readcount = 0;
  ppad_readcount = 0;
  ark_readcount = 0;
}

uint8_t get_pad0(void) {
  uint8_t value;
  ///  value = (uint8_t) retrieve_type(INP_JOYPAD0);
  value = 0;

  //  12, 33, 9, 10pin not usable

  if (digitalRead(PIN_A) == 1) value |= 1; //A
  if (digitalRead(PIN_B) == 1) value |= 2; //B
  if (digitalRead(PIN_SELECT) == 1) value |= 4; //SELECT
  if (digitalRead(PIN_START) == 1) value |= 8; //START
  if (digitalRead(PIN_UP) == 1) value |= 16; //UP
  if (digitalRead(PIN_DOWN) == 1) value |= 32; //DOWN
  if (digitalRead(PIN_LEFT) == 1) value |= 64; //LEFT
  if (digitalRead(PIN_RIGHT) == 1) value |= 128; //RIGHT

  if (digitalRead(PIN_SELECT) == 1 && digitalRead(PIN_START) == 1) NES_POWER = 0; //EXIT

  //EJECT EMULATOR 
  if (JOY_SHARE == 1 && JOY_OPTIONS == 1) {
    JOY_SHARE = 0;
    JOY_OPTIONS = 0;
    NES_POWER = 0;
  }

  if (JOY_SHARE == 1) value |= 8; //START
  if (JOY_OPTIONS == 1) value |= 4; //SELECT

  if (JOY_UP == 1) value |= 16; //UP
  if (JOY_DOWN == 1) value |= 32; //DOWN
  if (JOY_LEFT == 1) value |= 64; //LEFT
  if (JOY_RIGHT == 1) value |= 128; //RIGHT
  if (JOY_CROSS == 1) value |= 1; //A
  if (JOY_SQUARE == 1) value |= 2; //B
  ///  if (JOY_CIRCLE==1) Serial.println("JOY_CIRCLE");
  ///  if (JOY_TRIANGLE==1) Serial.println("JOY_TRIANGLE");

  // mask out left/right simultaneous keypresses
  if ((value & JOY_UP) && (value & JOY_DOWN)) value &= ~(JOY_UP | JOY_DOWN);
  if ((value & JOY_LEFT) && (value & JOY_RIGHT)) value &= ~(JOY_LEFT | JOY_RIGHT);
  // return (0x40 | value) due to bus conflicts
  ///return (0x40 | ((value >> pad0_readcount++) & 1));
  return (((value >> pad0_readcount++) & 1));
}
//********************************************************************************

//********************************************************************************
//BUFFER TEXT DRAW FUNCTIONS
#include "Retro8x16.c" //used font...

void screenmemory_fillscreen(uint8_t COLOR) {
  for (uint16_t Ypos = 0; Ypos < DEFAULT_HEIGHT; Ypos++)
    for (uint16_t Xpos = 0; Xpos < DEFAULT_WIDTH; Xpos++) {
      SCREENMEMORY[Ypos][Xpos] = COLOR;
    }

  if (LCD_ENABLED) xQueueSend(vidQueue, &SCREENMEMORY, 0); //refresh LCD
}
void screenmemory_drawpixel(uint16_t X, uint16_t Y, uint8_t COLOR) {
  if (Y < DEFAULT_HEIGHT && X < DEFAULT_WIDTH) SCREENMEMORY[Y][X] = COLOR;
}
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
void loop() {
}

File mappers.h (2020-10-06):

//--------------------------------------------------------------------------------
//MAPPERS !!!
//................................................................................
//MAPPER0
mapintf_t map0_intf =
{
  0, /* mapper number */
  "None", /* mapper name */
  NULL, /* init routine */
  NULL, /* vblank callback */
  NULL, /* hblank callback */
  NULL, /* get state (snss) */
  NULL, /* set state (snss) */
  NULL, /* memory read structure */
  NULL, /* memory write structure */
  NULL /* external sound device */
};
//................................................................................
//MAPPER1
/* TODO: roll this into something... */
 int bitcount = 0;
 uint8_t latch = 0;
 uint8_t regs[4];
 int bank_select;
 uint8_t lastreg;

 void map1_write(uint32_t address, uint8_t value)
{
  int regnum = (address >> 13) - 4;

  if (value & 0x80)
  {
    regs[0] |= 0x0C;
    bitcount = 0;
    latch = 0;
    return;
  }

  if (lastreg != regnum)
  {
    bitcount = 0;
    latch = 0;
    lastreg = regnum;
  }
  //lastreg = regnum;

  latch |= ((value & 1) << bitcount++);

  /* 5 bit registers */
  if (5 != bitcount)
    return;

  regs[regnum] = latch;
  value = latch;
  bitcount = 0;
  latch = 0;

  switch (regnum)
  {
    case 0:
      {
        if (0 == (value & 2))
        {
          int mirror = value & 1;
          ppu_mirror(mirror, mirror, mirror, mirror);
        }
        else
        {
          if (value & 1)
            ppu_mirror(0, 0, 1, 1);
          else
            ppu_mirror(0, 1, 0, 1);
        }
      }
      break;

    case 1:
      if (regs[0] & 0x10)
        mmc_bankvrom(4, 0x0000, value);
      else
        mmc_bankvrom(8, 0x0000, value >> 1);
      break;

    case 2:
      if (regs[0] & 0x10)
        mmc_bankvrom(4, 0x1000, value);
      break;

    case 3:
      if (mmc_getinfo()->rom_banks == 0x20)
      {
        bank_select = (regs[1] & 0x10) ? 0 : 0x10;
      }
      else if (mmc_getinfo()->rom_banks == 0x40)
      {
        if (regs[0] & 0x10)
          bank_select = (regs[1] & 0x10) | ((regs[2] & 0x10) << 1);
        else
          bank_select = (regs[1] & 0x10) << 1;
      }
      else
      {
        bank_select = 0;
      }

      if (0 == (regs[0] & 0x08))
        mmc_bankrom(32, 0x8000, ((regs[3] >> 1) + (bank_select >> 1)));
      else if (regs[0] & 0x04)
        mmc_bankrom(16, 0x8000, ((regs[3] & 0xF) + bank_select));
      else
        mmc_bankrom(16, 0xC000, ((regs[3] & 0xF) + bank_select));

    default:
      break;
  }
}

 void map1_init(void)
{
  bitcount = 0;
  latch = 0;

  memset(regs, 0, sizeof(regs));

  if (mmc_getinfo()->rom_banks == 0x20)
    mmc_bankrom(16, 0xC000, 0x0F);

  map1_write(0x8000, 0x80);
}

 void map1_getstate(SnssMapperBlock *state);
 void map1_getstate(SnssMapperBlock *state)
{
  state->extraData.mapper1.registers[0] = regs[0];
  state->extraData.mapper1.registers[1] = regs[1];
  state->extraData.mapper1.registers[2] = regs[2];
  state->extraData.mapper1.registers[3] = regs[3];
  state->extraData.mapper1.latch = latch;
  state->extraData.mapper1.numberOfBits = bitcount;
}


 void map1_setstate(SnssMapperBlock *state);
 void map1_setstate(SnssMapperBlock *state)
{
  regs[1] = state->extraData.mapper1.registers[0];
  regs[1] = state->extraData.mapper1.registers[1];
  regs[2] = state->extraData.mapper1.registers[2];
  regs[3] = state->extraData.mapper1.registers[3];
  latch = state->extraData.mapper1.latch;
  bitcount = state->extraData.mapper1.numberOfBits;
}

 map_memwrite map1_memwrite[] =
{
  { 0x8000, 0xFFFF, map1_write },
  {     -1,     -1, NULL }
};

mapintf_t map1_intf =
{
  1, /* mapper number */
  "MMC1", /* mapper name */
  map1_init, /* init routine */
  NULL, /* vblank callback */
  NULL, /* hblank callback */
  map1_getstate, /* get state (snss) */
  map1_setstate, /* set state (snss) */
  NULL, /* memory read structure */
  map1_memwrite, /* memory write structure */
  NULL /* external sound device */
};
//................................................................................
//MAPPER2
/* mapper 2: UNROM */
 void map2_write(uint32_t address, uint8_t value)
{
  UNUSED(address);

  mmc_bankrom(16, 0x8000, value);
}

 map_memwrite map2_memwrite[] =
{
  { 0x8000, 0xFFFF, map2_write },
  {     -1,     -1, NULL }
};

mapintf_t map2_intf =
{
  2, /* mapper number */
  "UNROM", /* mapper name */
  NULL, /* init routine */
  NULL, /* vblank callback */
  NULL, /* hblank callback */
  NULL, /* get state (snss) */
  NULL, /* set state (snss) */
  NULL, /* memory read structure */
  map2_memwrite, /* memory write structure */
  NULL /* external sound device */
};
//................................................................................
//MAPPER3
/* mapper 3: CNROM */
 void map3_write(uint32_t address, uint8_t value)
{
  UNUSED(address);

  mmc_bankvrom(8, 0x0000, value);
}

 map_memwrite map3_memwrite[] =
{
  { 0x8000, 0xFFFF, map3_write },
  {     -1,     -1, NULL }
};

mapintf_t map3_intf =
{
  3, /* mapper number */
  "CNROM", /* mapper name */
  NULL, /* init routine */
  NULL, /* vblank callback */
  NULL, /* hblank callback */
  NULL, /* get state (snss) */
  NULL, /* set state (snss) */
  NULL, /* memory read structure */
  map3_memwrite, /* memory write structure */
  NULL /* external sound device */
};
//................................................................................
//MAPPER4
 struct
{
  int counter, latch;
  bool enabled, reset;
} irq;

 uint8_t reg;
 uint8_t command;
 uint16_t vrombase;
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
